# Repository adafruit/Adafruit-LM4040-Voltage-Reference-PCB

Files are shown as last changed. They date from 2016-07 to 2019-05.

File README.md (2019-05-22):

## Adafruit LM4040 Voltage Reference PCB
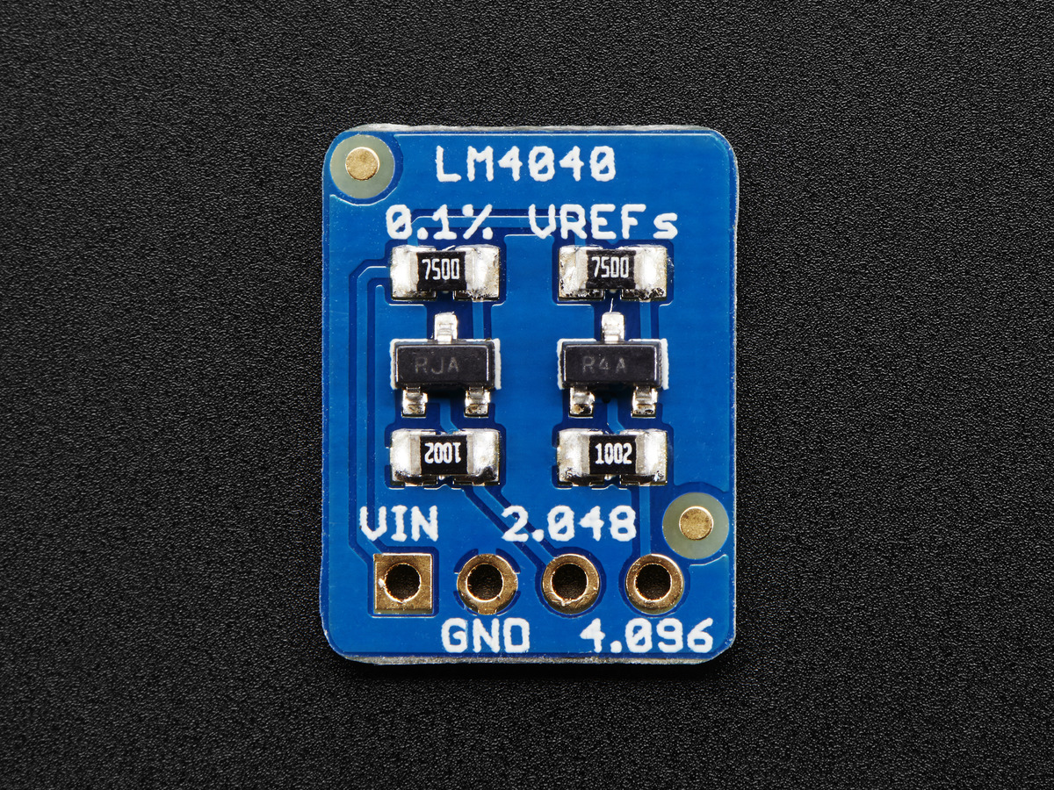
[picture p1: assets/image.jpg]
<a href="http://www.adafruit.com/products/2200"><br/>
Click here to purchase one from the Adafruit shop</a>

How good is your multimeter really?  Or maybe your analog converter needs a good reference? Or lets say you want to test your microcontroller's conversion accuracy & precision. If only you had a dependable, high precision, rock-solid voltage reference. Now you know why we made this very cute and useful little breakout board. It has two very high precision shunt-type voltage references with 750 ohm biasing resistors. One is 2.048V (great for 3.3V reference systems) and the other is 4.096 (great for 5V). Both are 0.1% accuracy!

Using is easy, just power with about 5V-12V, or 3V if you want only the 2V reference to work. Then measure the voltage on the output. Note that these are not regulators - you can't power anything off the output. They are for measurements only. For more details, check the LM4040 Datasheet for more information.

PCB files for the Adafruit LM4040 Voltage Reference. The format is EagleCAD schematic and board layout
- https://www.adafruit.com/products/2200

### License

Adafruit invests time and resources providing this open source design, please support Adafruit and open-source hardware by purchasing products from [Adafruit](https://www.adafruit.com)!

All text above must be included in any redistribution

Designed by Limor Fried/Ladyada for Adafruit Industries.
Creative Commons Attribution/Share-Alike, all text above must be included in any redistribution. 
See license.txt for additional information.

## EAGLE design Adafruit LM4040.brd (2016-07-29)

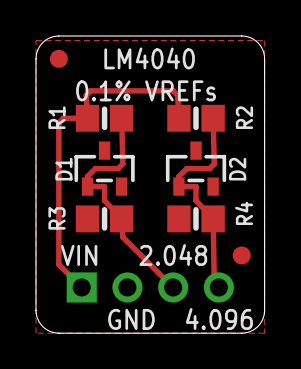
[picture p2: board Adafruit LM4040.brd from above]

Board: 2 copper layers, 12.7 x 16.5 mm, 10 parts (1 on the bottom side), 4 nets.

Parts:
D1: LM4040AIM3-2.0/NOPB; SOT23-R
D2: LM4040AIM3-4.1/NOPB; SOT23-R
FID1, FID2: FIDUCIAL""; FIDUCIAL_1MM
JP1: 1X04_ROUND
R1, R2: 750; 0805-NO
R3, R4: 10K; 0805-NO
U$5: ADAFRUIT_5MM

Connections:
2.048V: D1.1, JP1.3, R1.1, R3.1
4.096V: D2.1, JP1.4, R2.1, R4.1
GND: D1.2, D2.2, JP1.2, R3.2, R4.2
VIN: JP1.1, R1.2, R2.2

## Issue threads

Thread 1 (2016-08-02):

EagleCad can't open the sch file.

Koepel, 2016-08-02:
Eagle 7.5.0 and 7.6.0 in freeware mode can not open the sch file.

yashm, 2016-10-08:
Yes - the file is broken.
Here's the repaired file...
[Adafruit-LM4040-Voltage-Reference-PCB-master.zip](https://github.com/adafruit/Adafruit-LM4040-Voltage-Reference-PCB/files/517918/Adafruit-LM4040-Voltage-Reference-PCB-master.zip)

Koepel, 2016-10-08:
Thanks.
Those *.sch and *.brd files open without problem in eagle 7.6.0 and 7.7.0

yashm, 2016-10-08:
Glad I could help!

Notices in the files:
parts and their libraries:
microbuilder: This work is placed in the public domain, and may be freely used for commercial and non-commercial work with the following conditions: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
